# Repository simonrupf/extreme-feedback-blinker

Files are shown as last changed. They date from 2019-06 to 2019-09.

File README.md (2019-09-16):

# Extreme Feedback Blinker

A simple extreme feedback device (XFD) based on an ESP8266 microcontroller and
one or multiple WS2812 Neopixels, providing an HTTP GET interface over WiFi to
set the colors of the LEDs. The device is intended to be integrated into a CI/CD
or monitoring system providing a simple visual representation of the current
status.

## Usage

When first powered up, the WifiManager library will throw up a WLAN with SSID
"Blinker" and no password protection. When connecting to it using a WiFi enabled
device (notebook, smart phone, etc.), you should be redirected to a
configuration website that lets you select your main WLANs SSID and store the
WPA2 password on the microcontroller. Whenever the device is reset or powered up
*and* doesn't find the configured WiFi or fails to connect to it, it will return
to this configuration mode. The LED(s) should display red, blue, green as a test
pattern during this time.

Once connected to configured WLAN, the LEDs should start to shimmer in the
default color. At this point in time you can connect to the device via a
webbrowser to see a page with multiple buttons to change the color of the LEDs.
You can find the IP of the device via your DHCP servers leases.

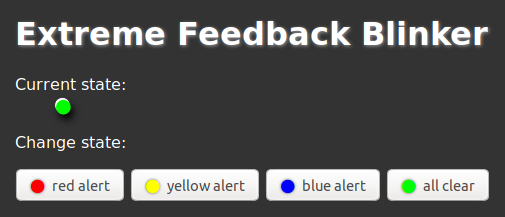
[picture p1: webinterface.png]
web interface, state set to "all clear"


The color is controlled via a GET parameter called "color" and expects the 24
bit RGB color in hexadecimal notation (like in CSS). Click the example buttons
to see some URLs with the codes for the labeled colors. It should be easy to
integrate such a URL into your CI/CD or monitoring system or you can call it in
your shell scripts using curl or wget.

In a production setup you would want to persist the IP address of the device and
give it a resolvable hostname in your DNS, so that you can replace the device
without changing your CI/CDs or monitoring systems configuration. If possible,
keep the device on a segregated WiFi SSID apart from other users. Set up packet
filter rules to only allow the necessary host to access the devices port 80.

## Prerequisites

- Any ESP8266 module, i.e. NodeMCU or Wemos D1 mini, etc.
- Arduino IDE setup to support your particular module
- one or multiple WS281**2**, WS281**2b** or WS281**3** Neopixels that are 3.3 V
  tolerant (not WS281**1**)
- jumper wires and bread board *or* light soldering skills and equipment

## Wiring

Example wiring of a NodeMCU with 470 Ohm resistor on the WS2812's data line:

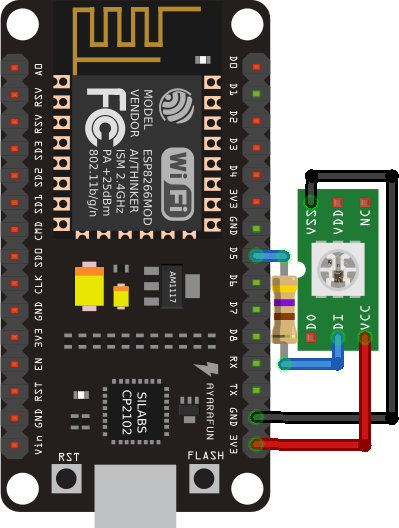
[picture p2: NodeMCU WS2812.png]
NodeMCU with WS2812 Neopixel


For a bare bones ESP-12 two pull-up/down resistors (10 kΩ) and a few capacitors
are needed when using 5 V USB power via a linear voltage regulator:

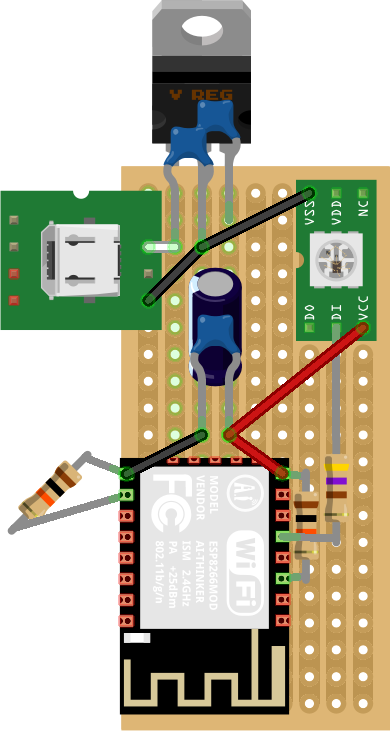
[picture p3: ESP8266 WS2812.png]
ESP-12 with WS2812 Neopixel


Capacitor ratings are:
- C1 100 nF (5 V to GND at voltage regulator)
- C2 2.2 µF (3.3 V to GND at voltage regulator)
- C3 470 µF (3.3 V to GND at ESP-12)
- C4 100 nF (3.3 V to GND at ESP-12)

Resistor ratings are:
- R3 10 kΩ (pull-down from ESP-12 GND to GPIO 15)
- R4 10 kΩ (pull-up from ESP-12 3.3 V to enable)
- R5 470 Ω (data line from ESP-12 GND to WS2812 data-in)

## Configuration

The Arduino sketch has a number of constants at the top that can be adjusted:
- `LED_NUM` - number of Neopixels you want to control, see note below
- `LED_PIN` - you can use any available digital pin to drive your pixels, pin
  14 lends itself as one of the PWM capable pins
- `ANIMATION_DELAY` - ms to wait between each color change, decrease to speed up
  the "breathing" animation of the colors
- `ANIMATION_MINIMUM` - the darkest the LEDs go before increasing their
  brightness, if set to 0 the LEDs will briefly turn off each cycle
- If you have a FLORA version 1 Neopixel, you also have to change `NEO_GRB +
  NEO_KHZ800` to `NEO_RGB + NEO_KHZ400`

> Note that while you may increase the number of pixels controlled, your NodeMCU
> powered via USB will probably not let you safely drive more then 5 pixels. For
> larger numbers please use an additional 3.3 V power supply, battery or similar
> and inject the power every 5 - 10 pixels or so. If using a power supply it is
> also advisable to add a large 1000 µF before the power gets injected to the
> pixels in order to prevent voltage bursts on power-up damageing your LEDs.

## Limitations

- By it's nature, black is displayed as the absence of light, so the LED will
  appear off. In general dark colors will appear dimmer then brighter ones.
- All content is served over HTTP only.
- There is no authentication implemented, anyone with access to that network
  can change the color.
- The microcontroller runs single-threaded and can only handle a single request
  at a time.
- The configuration page used to set the password of your WPA2 secured WLAN is
  served over an unsecured WiFi. The password is transmitted unencrypted.

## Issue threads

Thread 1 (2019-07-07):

Prevent caching of webinterface

simonrupf, 2019-07-07:
Due to caching, browsers may show an incorrect color in the "current state". Send a no-cache header to prevent this.

simonrupf, 2019-07-07:
Related: Even when the page is not cached, it will go stale if other users change the color. We could add an auto-refresh of the page every minute or so or also just a "refresh" button next to the current state.

Closed 2019-08-25.

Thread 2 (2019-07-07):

color transition

simonrupf, 2019-07-07:
While the colors are animated, switching them is instantaneous. It would be a nice touch if the switch from one color to another would occur in a short transition as well. Not too long, though as then the change may not be noticed as well, which would subvert the goal of an "extreme feedback device". Maybe 0.5 - 1s at most?

Closed 2019-08-25.

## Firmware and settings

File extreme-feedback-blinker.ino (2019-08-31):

#include <Arduino.h>
#include <ESP8266WiFi.h>
 
#include <DNSServer.h>        // Local DNS Server used for redirecting all requests to the configuration portal
#include <ESP8266WebServer.h> // Local WebServer to serve the configuration portal
#include <WiFiManager.h>      // Local AP with configuration portal for credentials

#include <Adafruit_NeoPixel.h>

#define LED_NUM 3
#define LED_PIN 14
#define ANIMATION_DELAY 750
#define ANIMATION_MINIMUM 28

Adafruit_NeoPixel led(LED_NUM, LED_PIN, NEO_GRB + NEO_KHZ800);
// Argument 1 = Number of pixels in NeoPixel strip
// Argument 2 = Arduino pin number (most are valid)
// Argument 3 = Pixel type flags, add together as needed:
//   NEO_KHZ800  800 KHz bitstream (most NeoPixel products w/WS2812 LEDs)
//   NEO_KHZ400  400 KHz (classic 'v1' (not v2) FLORA pixels, WS2811 drivers)
//   NEO_GRB     Pixels are wired for GRB bitstream (most NeoPixel products)
//   NEO_RGB     Pixels are wired for RGB bitstream (v1 FLORA pixels, not v2)
//   NEO_RGBW    Pixels are wired for RGBW bitstream (NeoPixel RGBW products)

ESP8266WebServer server(80);

// blue until initialized
String color = "0000ff";
uint8_t red   = 0;
uint8_t green = 0;
uint8_t blue  = 255;
uint8_t display_red   = 0;
uint8_t display_green = 0;
uint8_t display_blue  = 255;

bool animationDirection[LED_NUM];
uint8_t animationBrightness[LED_NUM];
uint16_t animationCounter = 0;

const char type[] PROGMEM = {"text/html"};
const char page[] PROGMEM = {
  "<!DOCTYPE HTML>\n"
  "<html>\n"
  "\t<head>\n"
  "\t\t<meta charset=\"utf-8\"/>\n"
  "\t\t<title>Extreme Feedback Blinker</title>\n"
  "\t\t<style>\n"
  "\t\t\tbody {\n"
  "\t\t\t\tfont-family: sans-serif;\n"
  "\t\t\t\tcolor: #fff;\n"
  "\t\t\t\tbackground-color: #333;\n"
  "\t\t\t\tmargin: auto;\n"
  "\t\t\t\twidth: max-content;\n"
  "\t\t\t}\n"
  "\t\t\th1 {\n"
  "\t\t\t\ttext-shadow: 1px 1px 3px #999;\n"
  "\t\t\t}\n"
  "\t\t\t.led:before {\n"
  "\t\t\t\tcontent: \"\\25CF\\00A0\";\n"
  "\t\t\t\tfont-size: 1.2em;\n"
  "\t\t\t}\n"
  "\t\t\tbutton .led:before {\n"
  "\t\t\t\ttext-shadow: 0 0 2px #666;\n"
  "\t\t\t}\n"
  "\t\t\t#state {\n"
  "\t\t\t\tcolor: #XXXXXX;\n"
  "\t\t\t\ttext-shadow: -1px -2px #fff, 3px 5px 7px #000;\n"
  "\t\t\t\tanimation-name: breathe;\n"
  "\t\t\t\tanimation-duration: 3s;\n"
  "\t\t\t\tanimation-iteration-count: infinite;\n"
  "\t\t\t}\n"
  "\t\t\t@keyframes breathe {\n"
  "\t\t\t\t0%   {opacity: 1;}\n"
  "\t\t\t\t50%  {opacity: 0.2;}\n"
  "\t\t\t\t100% {opacity: 1;}\n"
  "\t\t\t}\n"
  "\t\t</style>\n"
  "\t</head>\n"
  "\t<body>\n"
  "\t\t<h1>Extreme Feedback Blinker</h1>\n"
  "\t\t<dl>\n"
  "\t\t\t<dt>Current state:</dt>\n"
  "\t\t\t<dd><span id=\"state\" class=\"led\"></span> <a href=\"./\"><button style=\"float:right\">refresh</button></a></dd>\n"
  "\t\t</dl>\n"
  "\t\t<p>Change state:</p>\n"
  "\t\t<p>\n"
  "\t\t\t<a href=\"?color=ff0000\"><button><span class=\"led\" style=\"color:#f00;\"></span> red alert</button></a>\n"
  "\t\t\t<a href=\"?color=ffff00\"><button><span class=\"led\" style=\"color:#ff0;\"></span> yellow alert</button></a>\n"
  "\t\t\t<a href=\"?color=0000ff\"><button><span class=\"led\" style=\"color:#00f;\"></span> blue alert</button></a>\n"
  "\t\t\t<a href=\"?color=00ff00\"><button><span class=\"led\" style=\"color:#0f0;\"></span> all clear</button></a>\n"
  "\t\t</p>\n"
  "\t</body>\n"
  "</html>"
};

String getParam = "color";

void handleRoot() {
  Serial.println("request received");
  if (server.hasArg(getParam)) {
    color = server.arg(getParam);
    long colorNumber = (long) strtol(&color[0], NULL, 16);
    red   = colorNumber >> 16;
    green = colorNumber >> 8 & 0xFF;
    blue  = colorNumber & 0xFF;
    Serial.print("color code received: ");
    Serial.println(color);
    Serial.println("color decoded as:");
    Serial.print("- red   ");
    Serial.println(red);
    Serial.print("- green ");
    Serial.println(green);
    Serial.print("- blue  ");
    Serial.println(blue);
  }
  server.sendHeader("Cache-Control", "no-cache, max-age=0, must-revalidate, no-store");
  String content = FPSTR(page);
  content.replace("XXXXXX", color);
  server.send(200, FPSTR(type), content);
}

void handleAnimation() {
  updateColor(red, display_red);
  updateColor(green, display_green);
  updateColor(blue, display_blue);
  for (uint8_t i = 0; i < LED_NUM; ++i) {
    led.setPixelColor(
      i,
      led.Color(
        display_red   / 255.0 * animationBrightness[i],
        display_green / 255.0 * animationBrightness[i],
        display_blue  / 255.0 * animationBrightness[i]
      )
    );
    // handle animation loop
    if (animationDirection[i] && animationBrightness[i] < 255) {
      ++animationBrightness[i];
    } else if (animationBrightness[i] > ANIMATION_MINIMUM) {
      --animationBrightness[i];
    }
    if (animationBrightness[i] == ANIMATION_MINIMUM || animationBrightness[i] == 255) {
      animationDirection[i] = !animationDirection[i];
    }
  }
  led.show();
}

void updateColor(uint8_t & color, uint8_t & display_color) {
  if (color > display_color) {
    ++display_color;
  } else if (color < display_color) {
    --display_color;
  }
}

void setup() {
  Serial.begin(115200);
  delay(10);
  Serial.println("");
  Serial.println("");

  // Initialize the NeoPixel
  led.begin();            // INITIALIZE NeoPixel strip object (REQUIRED)
  led.show();             // Turn OFF all pixels ASAP
  led.setBrightness(255); // Set BRIGHTNESS to maximum
  // test pattern red, green, blue
  led.setPixelColor(0, led.Color(255, 0, 0));
  led.setPixelColor(1, led.Color(0, 255, 0));
  led.setPixelColor(2, led.Color(0, 0, 255));
  led.show();

  // Initialize animation arrays, so all pixels start at a different part of the cycle
  for (uint8_t i = 0; i < LED_NUM; ++i) {
    animationDirection[i]  = (i == LED_NUM - 1);
    animationBrightness[i] = ceil(255 - (255 / (LED_NUM - 1) * i));
    if (animationBrightness[i] < ANIMATION_MINIMUM) {
      animationBrightness[i] = ANIMATION_MINIMUM;
    }
  }

  // Connect to WiFi network
  WiFiManager wifiManager;
  wifiManager.autoConnect("Blinker");
  Serial.print("WiFi connected to ");
  Serial.println(WiFi.SSID());

  // Start the server
  server.on("/", handleRoot);
  server.begin();
  Serial.println("Server started");
 
  // Print the IP address
  Serial.print("Use this URL to connect: ");
  Serial.print("http://");
  Serial.print(WiFi.localIP());
  Serial.println("/");
}
 
void loop() {
  // Check if a client has connected
  server.handleClient();

  // set colors only after a certain delay to avoid flickering
  if (animationCounter >= ANIMATION_DELAY) {
    handleAnimation();
    animationCounter = 0;
  } else {
    ++animationCounter;
  }
}

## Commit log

2019-06-11 importing prototype sketch from Arduino IDE
2019-06-11 documenting wiring using fritzing
    [ESP8266 WS2812.fzz, NodeMCU WS2812.fzz]
2019-06-12 initialize animation state automatically based on number of LEDs, improve documentation
2019-06-12 adding display of current state, playing around with CSS
2019-08-25 add Gerber files for PCB printing
2019-08-25 3 LEDs looks best (like twinkling stars), 5 or more makes it look like a warp core
    [extreme-feedback-blinker.ino]
2019-08-25 ensure page isn't cached when going back and adding a refresh button, fixes #1
    [extreme-feedback-blinker.ino]
2019-08-25 animate transition between colors, fixes #2
    [extreme-feedback-blinker.ino]
2019-09-16 fixing reverted USB connector on PCB, improving documentation with BOM matching the PCB
    [ESP8266 WS2812.fzz]
